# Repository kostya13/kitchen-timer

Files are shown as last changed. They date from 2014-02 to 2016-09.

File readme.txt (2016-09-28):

* Устройство "Программируемый кухонный таймер".

Автор: Константин Ильяшенко <kx13@ya.ru>

** Введение

Данное устройство представлет собой программируемый таймер, выполненный на микроконтроллере
ATTINY2313 и снабженный светодиодным семисегментным индикатором.
A внутре у него думатель и неонка :)

Я старался сделать управление как можно простым и удобным.

Так как на кухне обычно используется несколько типовых предустановок таймера, то 
их можно запрограммировать на определенные кнопки и затем выставлять время одним нажатием.

Назначение клавишам предустановленных значений, позволяет одним нажатием установить время больше 9 минут, 
а так же одним нажатием переустановить таймер на новое значение. Такие операции гораздо быстрее, чем многократное
нажатие на клавиши "+" "-" или кручение ручкой (особенно если надо переустановить таймер на то же время).

Допустим пельмешки варятся 7 минут, яйца 10, а блинчики надо переворачивать через 2 минуты.
Можно настроить эти таймеры на кнопки 1, 2 и 3 и после включения устройства, например, нажать
2, чтобы влючить таймер для варки яиц.

Если же вы решили, что с сегодняшнего дня яца будете варить 11 минут, ничего страшного, можете тут
же перепрограммировать кнопку 2 на 11 минут.

Схема достаточно проста:
scheme/timer.png

** Характеристики                                            

Диапазон отсчета от 1 до 99 минут.
Кнопками * и  # можно  в любой момент изменять текущее значение таймера.

После включения устройство находится в режиме ожидания.
Нажав кнопку от 1 до 0 можно выбрать заранее установленное время.

В любой момент можно переустановить таймер, нажав нужную кнопку.

При удержании цифровой кнопки более 4 секунд, произойдет запись текущего значения таймера
в ячейку с номером кнопки. Новые значения записываются в eeprom память.

Нажатия на кнопки и операция записи сопровождаются звуковой индикацией.

Звук окончания периодически повторяется после окончания счета, на случай если не был услышен
первый сигнал. Таймер будет пищать пока его не выключат или не запустят новый отсчет.

Работает устройство от 2 батареек AA. По сути, любой источник питания 3В. Возможна
работа и с 5В питанием.

** Программное обеспечение

Программа написана для компилятора gcc, поэтому в Windows используется пакет WinAVR. 
В Linux пакет avr-gcc.

Программа позволяет настраивать  частоту и длительность звучания для звука клавиш и 
звука окончания отсчета. Можно даже составить простенькую мелодию.

Так же настраивается время реакции на кнопки. Реализуется алгоритм предотвращения дребезга.

Сборка программы осуществляется командой
make build.

Фьюзы установленны по умолчанию: 
Low 0x64; High 0xdf; Extended 0xff.
Поэтому на новом контроллере их можно не трогать.
Ключи для прошивки фьюзов программы avrdude:
-U lfuse:w:0x64:m -U hfuse:w:0xdf:m -U efuse:w:0xff:m 

На страничке http://www.engbedded.com/fusecalc можно посомтреть более подробную расшифровку значений.
Так же есть файл fuses.png в каталоге проекта.

Компилятор для Windows можно взять здесь:
http://sourceforge.net/projects/winavr/

Какие пакеты нужны для сборки в  Linux можно почитать здесь:
http://avr.ru/tools/linux/dev

Для прошивки я использовал программу avrdude.
Пример команды для прошивки:
avrdude -p t2313 -c usbasp -U flash:w:kt.hex
Если в Makefile все параметры указаны верно, можно запустить прошивку командой
make program

При сборке создается файл с раширенийем eep. Его можно залить в eeprom контроллера, чтобы сбросить все установленные
значения таймера.

Программу я старался сделать как можно более простой и понятной. 

** Аппаратное обеспечение

Таймер выполнен на микроконтроллере ATTINY2313, причем задействованы все возможные выводы контроллера.

Так как для этого таймера не нужна высокая точность, то контроллер тактуется внутренним генератором. Частота работы 1МГц.

В качестве индикатора выбран двухсимвольный светодиодый индикатор с общим АНОДОМ. 

Транзисторы обычные маломощные n-p-n структуры. Я взял КТ315. Можно любой аналог.
Базовые резисторы R1 - R3 номиналом 1кОм, мощность 0,125Вт.

Для вывода звука, можно применять небольшой динамик сопротивлением 8 Ом  и мощностью 0,25Вт. 
Или можно использовать пьезоизлучатель. В этом случае для получения максимальной громкости
надо настроить частоту звука окончания счета на резонансную частоту излучателя (ее можно
посмотреть в документации на излучатель). Так же можно подобрать излучатель с максимальной
громкостью. Поэтому я считаю применение излучателей более практично.

Выводы контроллера, управляющие сегментами (ноги с 12 по 18) подключены напрямую т.к. питание низкое и вдобавок
динамическое управление дают небольшой ток. Если питать от 5В источника питания то необходимо
эти ножки подключать через резисторы примерно на 68Ом.

Клавиатура матричная, телефонного типа. В принципе, можно сделать из 12 отдельных кнопок.
Можно обойтись и меньшим количеством кнопок, если не нужно все 10 программ.

Все схемы  нарисованы в программе kicad.
Скачть программу можно здесь:
http://www.kicad-pcb.org/display/KICAD/Download

Для того, чтобы размещать несколько  плат на печатном листе я использовал пакет Latex.
Makefile и шаблон LaTeX для этого дела размещен в каталоге scheme.

Печатная плата сделана под готовый корпус, поэтому будет врядли полезна, но учитывая простоту схемы
нарисовать универсальную плату не составит большого труда.

** Ссылки

Скачать последнюю версию:
https://bitbucket.org/kostya13/kitchen-timer/downloads

Если у вас установлен Mercurial, можно просто клонировать проект:
hg clone https://bitbucket.org/kostya13/kitchen-timer

В проекте имеется как исходный код, так иготовая прошивка для этого кода.
Ппринципиальной схема в виде рисунка в формате png.
Электрические схемы для программы kicad.

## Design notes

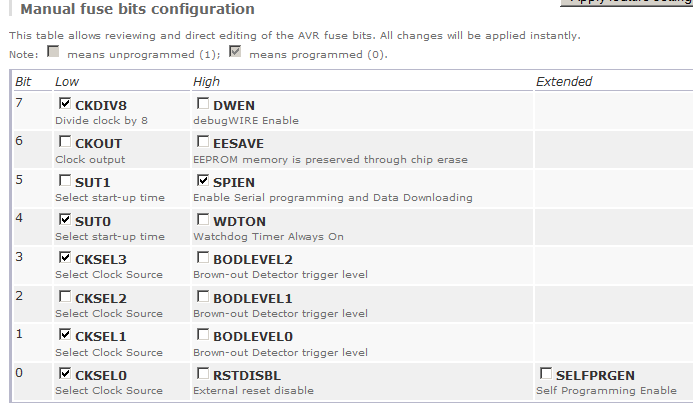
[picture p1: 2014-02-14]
fuses.png

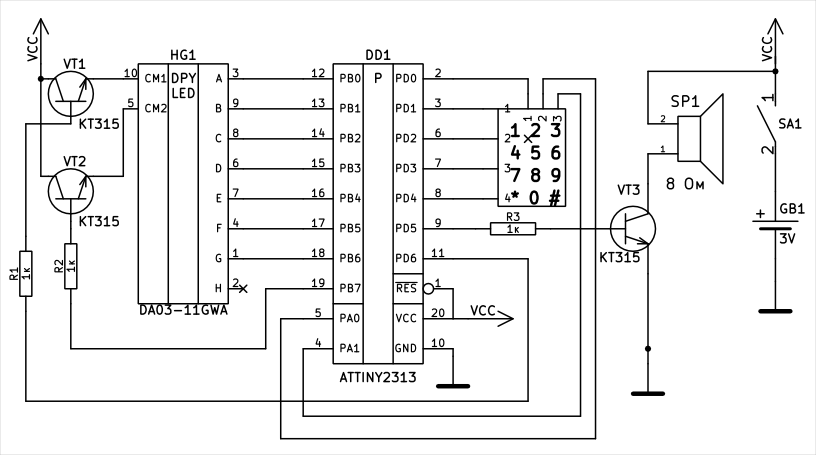
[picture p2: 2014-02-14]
schema/timer.png

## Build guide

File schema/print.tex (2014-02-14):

% Шаблон  документа для печати нескольких печатных плат на одном листе.
% параметр scale указывается, если принтер неправильно печатает размеры
\documentclass[12pt,a4paper,final]{letter}
\usepackage[top=1.5cm,bottom=1.5cm,left=1.5cm,right=1.5cm]{geometry}
\usepackage{fancyhdr}
\usepackage[pdftex]{graphicx}
\renewcommand{\headrulewidth}{0pt}
\begin{document}
\pagestyle{fancy}
{}
\hspace{2.0cm}
{}
\hspace{2.0cm}
{}

\vspace{2.0cm}
{}
\hspace{2.0cm}
{}
\hspace{2.0cm}
{}

\vspace{2.0cm}
{}
\hspace{2.0cm}
{}
\hspace{2.0cm}
{}

\vspace{2.0cm}
{}
\hspace{2.0cm}
{}
\hspace{2.0cm}
{}

\end{document}

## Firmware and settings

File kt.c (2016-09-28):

// -*- coding: utf-8 -*-

// Февраль 2014г. Константин Ильяшенко <kx13@ya.ru>

// Макросы:
// F_CPU - частота процессора
// MCU - тип микроконтроллера
// определены в Makefile

#include <avr/io.h>
#include <avr/interrupt.h>
#include <avr/eeprom.h>
#include <avr/pgmspace.h>
#include <inttypes.h>
#include <util/delay.h>

#define TIMER_FREQ 100UL // Требуемая частота таймера (Герц)
#define TIMER_PRESCALER 1 // Установить значение делителя таймера в TCCR1B (Bits 2:0)

#define MAX_TIMER  (F_CPU / TIMER_PRESCALER) / TIMER_FREQ // максимальное значение таймера в режиме CTC
#if MAX_TIMER > UINT16_MAX
// значение MAX_TIMER слишком большое, необходимо увеличить TIMER_PRESCALER.
# error "MAX_TIMER too large, need increase TIMER_PRESCALER."
#endif

#define low(x)  ((x) & 0xFF)
#define high(x) (((x) >> 8) & 0xFF)

#define set_bit(port,bit)   port |= _BV(bit)
#define reset_bit(port,bit) port &= ~(_BV(bit))

#define STOP_BEEP() reset_bit(TCCR0A, COM0B0)
#define START_BEEP() set_bit(TCCR0A, COM0B0)

const uint16_t MAIN_TIMER_MAX = 60 * (TIMER_FREQ - 1); // количество отчсетов таймера за 1 минуту
const uint16_t REBEEP_TIMER_MAX = 20 * TIMER_FREQ; // пауза между повторными сигналами

const uint8_t MAX_COUNT_VALUE = 99;

const uint8_t KEY_TIME = 1;    // время задержки при нажатии на клавиши (n/TIMER_FREQ)*4 (сек.)
const uint8_t SAVE_TIME = 100; // так как проверяется после 4 проходов по строкам

//формула расчета коэффициента для требуемой частоты
// OCRA = F_CPU / (2 * N * FREQ) - 1
// F_CPU - частота процессора, N - делитель счетчика, FREQ - заданная застота звука
const uint8_t KEY_FREQ = 200; // частоты пищалки для разных типов событий
//если используется пьезоизлучатель, то для максимальной громкости небходимо
//установить резонансную частоту излучателя
const uint8_t END_FREQ = 25;
const uint8_t SAVE_FREQ = 150;

const uint8_t SHOW_TIME = 1; // время свечения одного сегмента индикатора

enum KEYS {HASH_KEY = -1, STAR_KEY = -2};
enum NO_ACTION {NO_KEY_PRESSED = -4, NOT_USED = 5, STOP = -1};
enum BEEP_STATUS {BEEP_ON, BEEP_OFF};
enum YES_NO {NO = 0, YES = 1};
enum STATES {STATE_COUNTING, STATE_WAIT};
enum KEY_ACTIONS {ACTION_NONE, ACTION_PRESSED, ACTION_SAVE};

typedef struct beep_struct
{
  int8_t enable; // состояние вывода звука (включен или выключен)
  uint8_t position; // позиция в массиве звука
  const int8_t *sound; //выбраный массив звука
  uint8_t play; // счетчик длительности звука
  uint8_t repeat; // флаг повторного включения звука
  uint16_t pause; // пауза между повторами
} CurrentBeep;

typedef struct led_struct
{
  uint8_t first_digit;
  uint8_t second_digit;
} Led;

typedef struct key_struct
{
  int8_t pressed; // номер нажатой кнопки
  int8_t used;    // кнопка была использована
  int8_t action; // действие для нажатой кнопки
} Key;

typedef struct counter_struct
{
  uint8_t current; // значение счетчика
  uint8_t last; // предыдущее значение
  uint8_t index; // номер выбранного счетчика
  uint8_t finished; // флаг окончания счета
  uint16_t fraction; // отсчитывает доли для current
} Counter;


//Звуки для разных событий.
//Формат:
//Положительные числа задают длительность звучения, отрицательные - длительность паузы,
//Специальное значение STOP означает конец звучания.
//Время звучания определяется как n/TIMER_FREQ.
//Т.е если TIMER_FREQ=100, то при n=100 будет пищать 1 секунду
//максимальное значение числа: от -127 до +127.
//Если необходима большая длительность можно поставить несколько значений звучания подряд.
const int8_t key_beep[] = {2, STOP};
const int8_t end_beep[] = {20, -3,  20, -3, 20, STOP};
const int8_t save_beep[] = {10, -10,  10, STOP};

//значения таймера по умолчанию
const uint8_t timer_preset_default[10] PROGMEM = {99, 10, 20, 30, 40, 50, 60, 70, 80, 90};
//значения таймера в EEPROM по умолчанию. Загружаются в контроллер отдельной командой
uint8_t EEMEM timer_preset[10] = {0xFF, 0xFF, 0xFF, 0xFF, 0xFF, 0xFF, 0xFF, 0xFF, 0xFF, 0xFF};

const int8_t keyboard_decoder[4][3] PROGMEM = {{ 1, 2, 3}, { 4, 5, 6}, {7, 8, 9}, {STAR_KEY, 0, HASH_KEY}};
const int8_t led_digits[] PROGMEM = {64, 121, 36, 48, 25, 18, 2, 120, 0, 16};

volatile CurrentBeep beep;
volatile Key key;
volatile Counter counter;

inline void led_set(Led *led)
{
  led->first_digit = pgm_read_byte(&led_digits[counter.current / 10]);
  led->second_digit = pgm_read_byte(&led_digits[counter.current % 10]);
}

inline static void led_show(Led led)
{
  PORTB = led.second_digit;
  set_bit(PORTB, PINB7);
  _delay_ms(SHOW_TIME);

  PORTB =  led.first_digit;
  set_bit(PORTD, PIND6);
  _delay_ms(SHOW_TIME);
  reset_bit(PORTD, PIND6);
}

inline void start_beep(const int8_t* set_beep, uint8_t freq)
{
  beep.position = 1;
  beep.sound = set_beep;
  beep.play = beep.sound[0];
  OCR0A = freq;
  set_bit(TCCR0A, COM0B0);
  beep.enable = BEEP_ON;
}

inline void check_beep(void)
{
  if (beep.enable != BEEP_ON)
    return;

  if(beep.play > 0)
  {
    beep.play--;
    return;
  }
  
  int8_t current = beep.sound[beep.position];
  int8_t pause_flag = current & 0x80;
  int8_t delay;

  if (current == STOP)
  {
    beep.enable = BEEP_OFF;
    STOP_BEEP();
    return;
  }

  if (pause_flag)
  {
    STOP_BEEP();
    delay = -1 * current;
  }
  else 
  {
    START_BEEP();
    delay = current;
  }
  
  beep.play = delay;
  beep.position++;

}

inline static void scan_keyboard(void)
{
  static const uint8_t START_ROW = 1; // номера битов порта для сканирования строк клавиатуры
  static const uint8_t END_ROW = 4;

  static int8_t current_key = NO_KEY_PRESSED ;
  static int8_t last_key = NO_KEY_PRESSED ;
  static uint8_t pressed_time = 0;
  static int8_t current_row = START_ROW ;

  reset_bit(PORTD, current_row);

  if (current_row == START_ROW)
    current_key = NO_KEY_PRESSED;

  uint8_t column0 = (~PIND) & 0x01;
  uint8_t column1 = (~PINA) & 0x01;
  uint8_t column2 = (~PINA) & 0x02;

  int8_t shift = -1;
  if(column0)
    shift = 0;
  else if (column1)
    shift = 1;
  else if(column2)
    shift = 2;
  if ( shift >= 0)
    current_key = pgm_read_byte(&keyboard_decoder[current_row-1][shift]);
  
  set_bit(PORTD, current_row);
  current_row++;

  if (current_row < END_ROW + 1)
    return;
  
  if (current_key != NO_KEY_PRESSED && pressed_time <  UINT8_MAX)
    pressed_time++;

  if( current_key == NO_KEY_PRESSED)
  {
    if(pressed_time > KEY_TIME && pressed_time < SAVE_TIME)
      key.action = ACTION_PRESSED;

    pressed_time = 0;
    key.used = NOT_USED;
  }
  else if (pressed_time > SAVE_TIME && key.used == NOT_USED)
  {
    key.action = ACTION_SAVE;
  }
  
  current_row = START_ROW;
  key.pressed = last_key;
  last_key = current_key;
}

inline uint8_t is_digit_key(void)
{
  return key.pressed >= 0 && key.pressed <= 9;
}

uint8_t key_pressed(void)
{
  if(key.action != ACTION_PRESSED)
  {
    return NO;
  }

  if(is_digit_key())
  {
    counter.current = eeprom_read_byte(&timer_preset[key.pressed]);
    if ((counter.current > MAX_COUNT_VALUE) || (counter.current == 0))
    {
      counter.current = pgm_read_byte(&timer_preset_default[key.pressed]);
    }
  }
  else if(key.pressed == STAR_KEY)
  {
    counter.current--;
    if (counter.current == 0)
    {
      counter.current = MAX_COUNT_VALUE;
    }
  }
  else if(key.pressed == HASH_KEY)
  {
    counter.current++;
    if(counter.current > MAX_COUNT_VALUE)
    {
      counter.current = 1;
    }
  }
  else
  {
    return NO;
  }

  start_beep(key_beep, KEY_FREQ);
  counter.fraction = 0;        
  counter.finished = NO;
  key.action = ACTION_NONE;
    
  return YES;
}

inline void end_count(void)
{
  start_beep(end_beep, END_FREQ);
  beep.pause = 0;      
  beep.repeat = NO;
}

ISR (TIMER1_COMPA_vect)
{
  if(counter.current > 0)
  {
    if (counter.fraction == MAIN_TIMER_MAX)
    {
      counter.fraction = 0;
      counter.current--;
    }
    else
      counter.fraction++;
  }
  
  if(counter.finished == YES)
  {
    if (beep.pause == REBEEP_TIMER_MAX)
    {
      beep.repeat = YES;
      beep.pause = 0;
    }
    else
      beep.pause++;
  }
  
  return;
}

ISR (TIMER1_COMPB_vect)
{
  scan_keyboard();
  check_beep();
}

int main(void)
{
  //все ножки на вход
  DDRA = 0x00;
  //вклчаем подтягивающие резисторы
  PORTA = 0xFF;

  // все ножки на выход
  DDRB = 0xFF;
  // везде лог.0
  PORTB = 0x00 ;


  // указаные дорожки на выход.
  DDRD = _BV(PIND1) | _BV(PIND2) | _BV(PIND3) |_BV(PIND4) | _BV(PIND5)  | _BV(PIND6);
  // на 0 ножку уст. резистор, ножки 1-4 перевести в лог.1.
  PORTD = _BV(PIND0) | _BV(PIND1) |_BV(PIND2) | _BV(PIND3)  | _BV(PIND4);

  // CTC mode
  TCCR0A =  _BV(WGM01);
  //prescaler at 8
  TCCR0B = _BV(CS01);
  TCNT0 = 0x00;
  // max value
  OCR0A = 130;
  OCR0B = 0;

  TCCR1A = 0x00;
  TCCR1B =_BV(WGM12) | _BV(CS10); //CTC mode, prescaler 1
  TCNT1H = 0x00;
  TCNT1L = 0x00;
  ICR1H = 0x00;
  ICR1L = 0x00;
  OCR1AH = high(MAX_TIMER);
  OCR1AL = low(MAX_TIMER);
  OCR1BH = 0x00;
  OCR1BL = 0x00;

  // прерывания от таймеров
  TIMSK = _BV(OCIE1A) | _BV(OCIE1B);

  // выключаем Universal Serial Interface
  USICR=0x00;

  // выключаем Analog Comparator 
  ACSR=0x80;

  
  beep.enable = BEEP_OFF;

  key.pressed = NO_KEY_PRESSED;
  key.action = ACTION_NONE;
  key.used = NOT_USED;

  // сразу после включения таймер будет периодически пищать
  // чтобы напомнить, что он включен
  counter.current = 0;
  counter.finished = YES;
  counter.last = counter.current;

  beep.repeat = NO;
  beep.pause = 0;        

  Led led_display;
  led_set(&led_display);

  int8_t state = STATE_WAIT;
  sei();
  while (1)
  {
    switch(state)
    {
    case STATE_WAIT:
      if(beep.repeat == YES)
      {
        end_count();
      }
      
      if(key_pressed())
        state = STATE_COUNTING;
      break;
     
    case STATE_COUNTING:
      key_pressed();

      if( key.action == ACTION_SAVE)
      {
        if(is_digit_key()) 
        {
          start_beep(save_beep, SAVE_FREQ);
          eeprom_write_byte(&timer_preset[key.pressed], counter.current);
        }
        key.used = key.pressed;
        key.action = ACTION_NONE;
      }
      
      if(counter.current == 0)
      {
        end_count();        
        counter.finished = YES;
        state = STATE_WAIT;
      }
      break;
      
    default:
      state = STATE_WAIT;
    }
    
    if(counter.current != counter.last)
    {
      led_set(&led_display);
      counter.last = counter.current;
    }

    led_show(led_display);
  }
  return 0;
}

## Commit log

2014-02-04 add kicad fies
    [timer.sch]
2014-02-07 next step
    [timer.kicad_pcb, timer.sch]
2016-09-16 Сменил кодировку на utf-8
2016-09-16 Исправлена кодировка
2016-09-28 Удален ненужный include
